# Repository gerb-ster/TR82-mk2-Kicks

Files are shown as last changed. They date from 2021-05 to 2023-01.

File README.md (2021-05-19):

# TR82 mk2 'Kicks'

Second version of the TR82 project; proper PCB's this time! I've combined the BassDrums and the SnareDrum to 
a single board. I've added a OpAmp buffer to the output and changed the output impedance to a more standard
1k. Next to that I've also added a Gate-to-Trigger circuit based on a design by Ken Stone. It converts the 
rising edge of a Gate signal into a short trigger pulse. By changin the level of the gate/trigger input you
can control how 'hard' you hit the drums. Higher levels means more 'accent'.

The Designs and Mods of the drum voices are the same as in the 'original' TR82.

There is a 'internal trigger' connection added to the mainboard of the PCB. This can be used to hook it up to
a seperate controller board. Maybe :). 

### Links

https://www.gerbster.nl/tr82/  
https://www.elby-designs.com/webtek/cgs/cgs24/cgs24_gatetotrigger.html

## Status: Work in Progress

- done: first schematic & board design
- done: breadboard and test
- done: design frontpanel
- todo: order PCB and build prototype

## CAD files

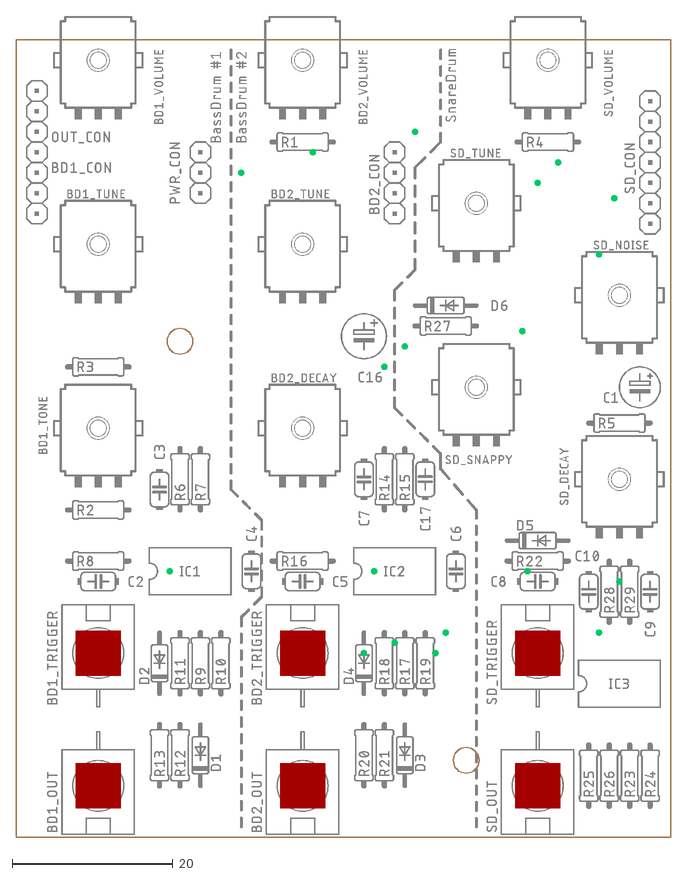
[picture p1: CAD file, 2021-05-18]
faceplates/ioboard.dxf
81.3 x 102.0

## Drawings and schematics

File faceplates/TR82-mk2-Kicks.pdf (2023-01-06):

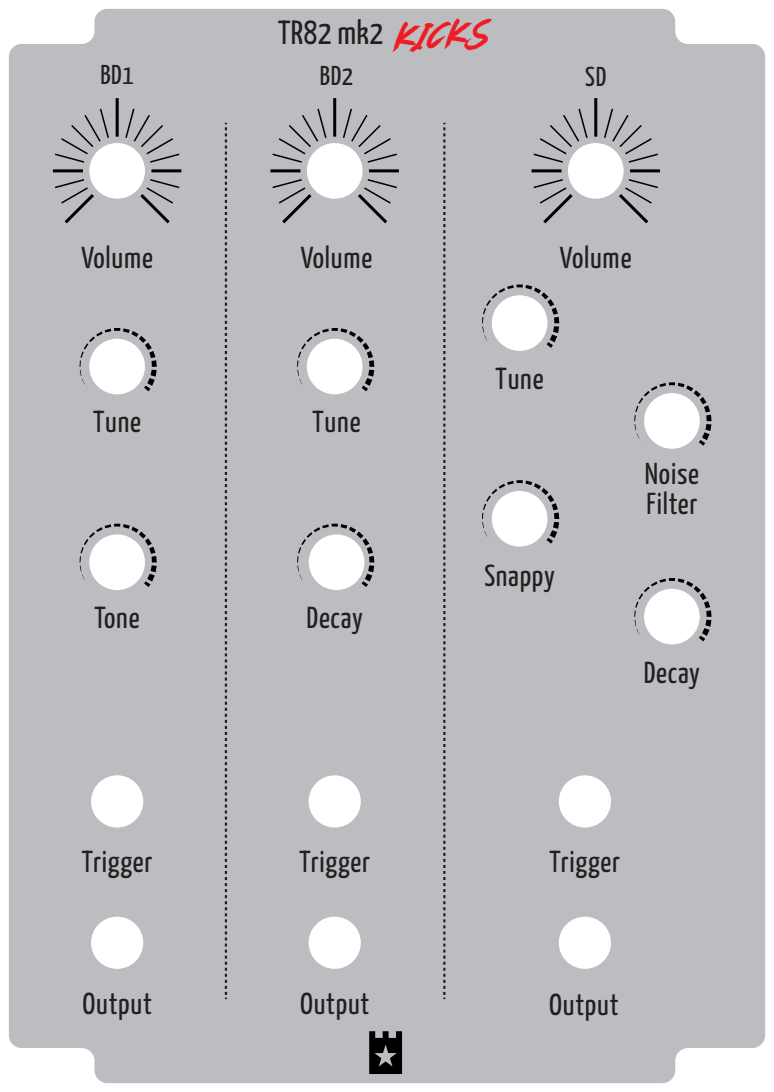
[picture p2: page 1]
Volume; Trigger; Output; Tune; Tone; Decay; Noise Filter; Snappy; Kicks

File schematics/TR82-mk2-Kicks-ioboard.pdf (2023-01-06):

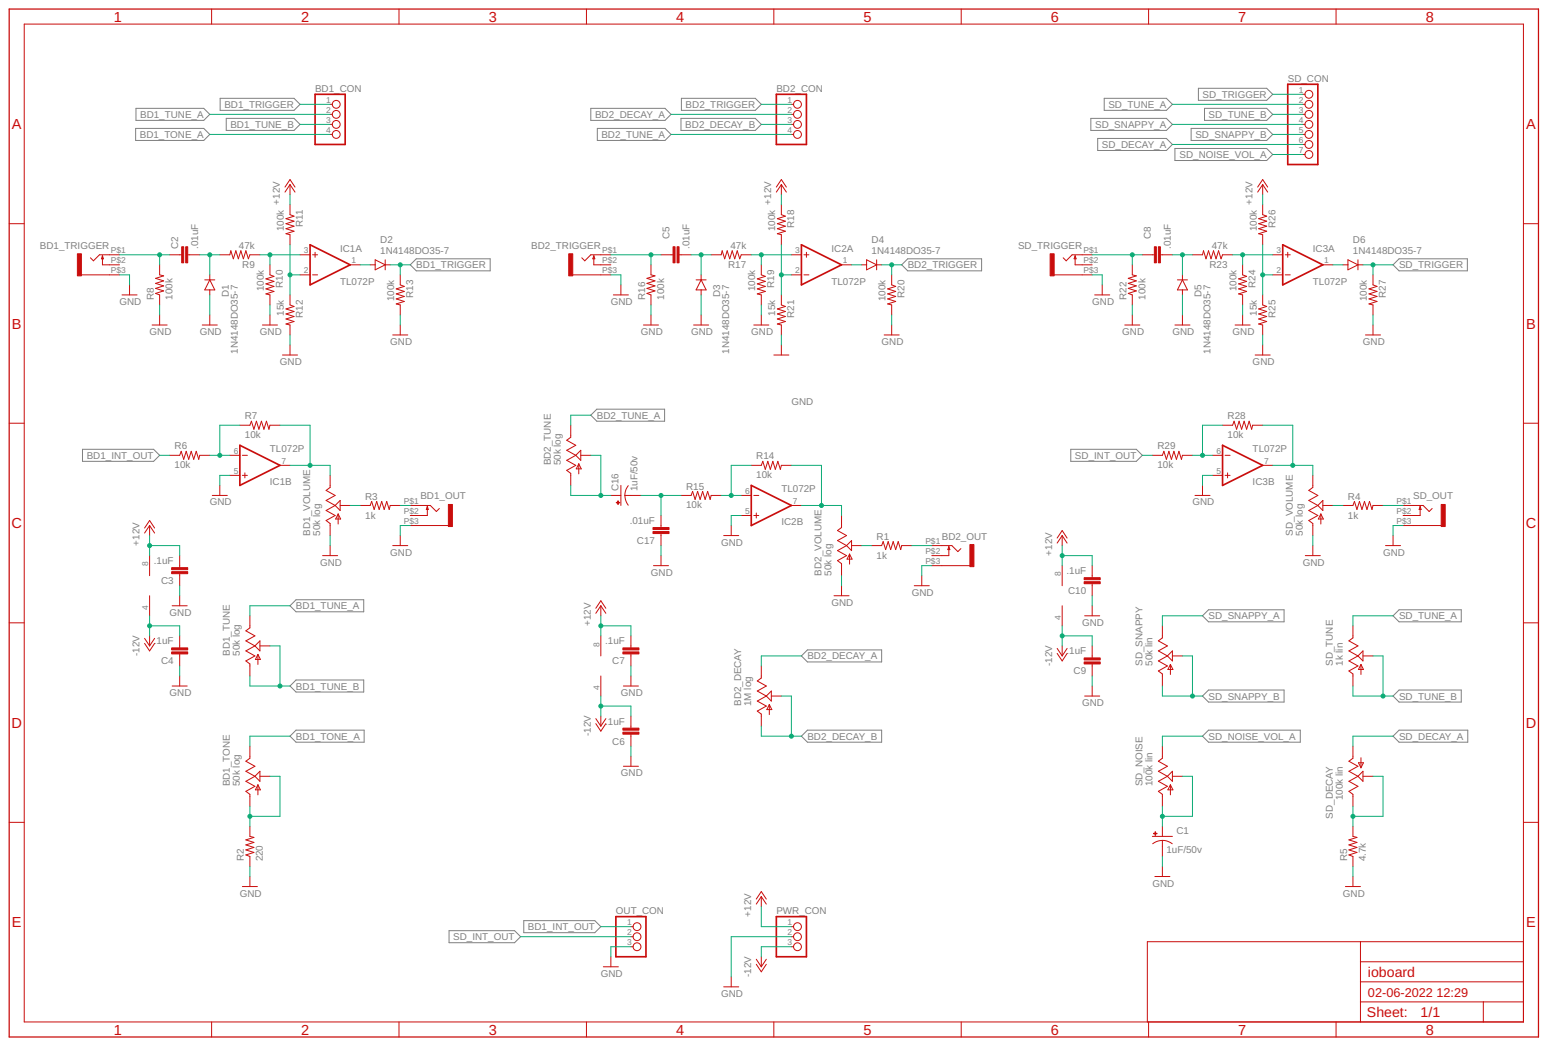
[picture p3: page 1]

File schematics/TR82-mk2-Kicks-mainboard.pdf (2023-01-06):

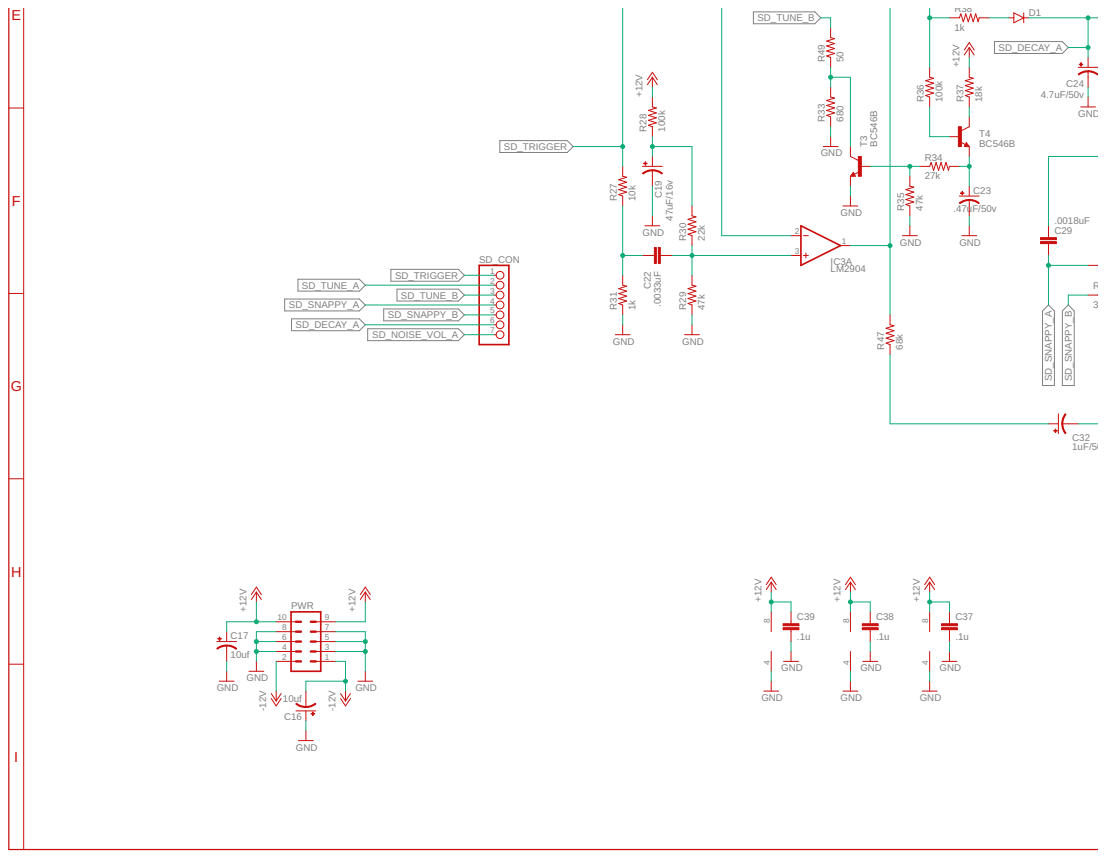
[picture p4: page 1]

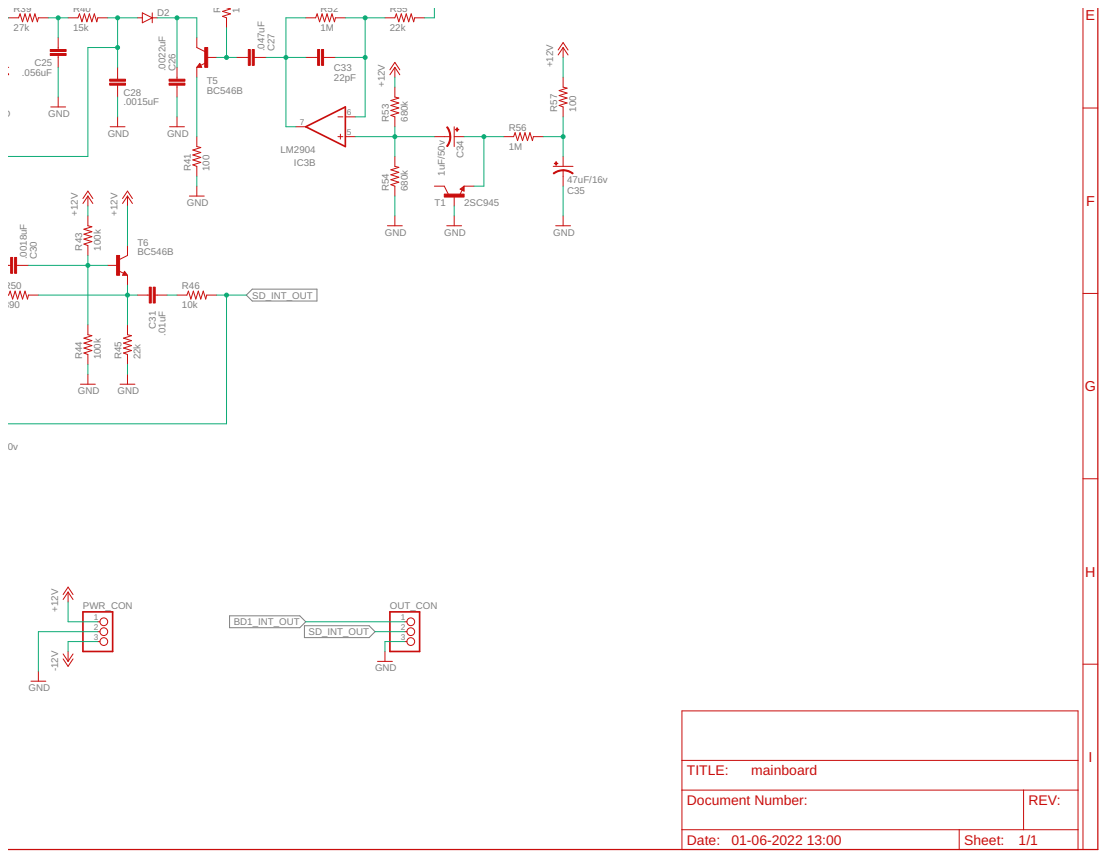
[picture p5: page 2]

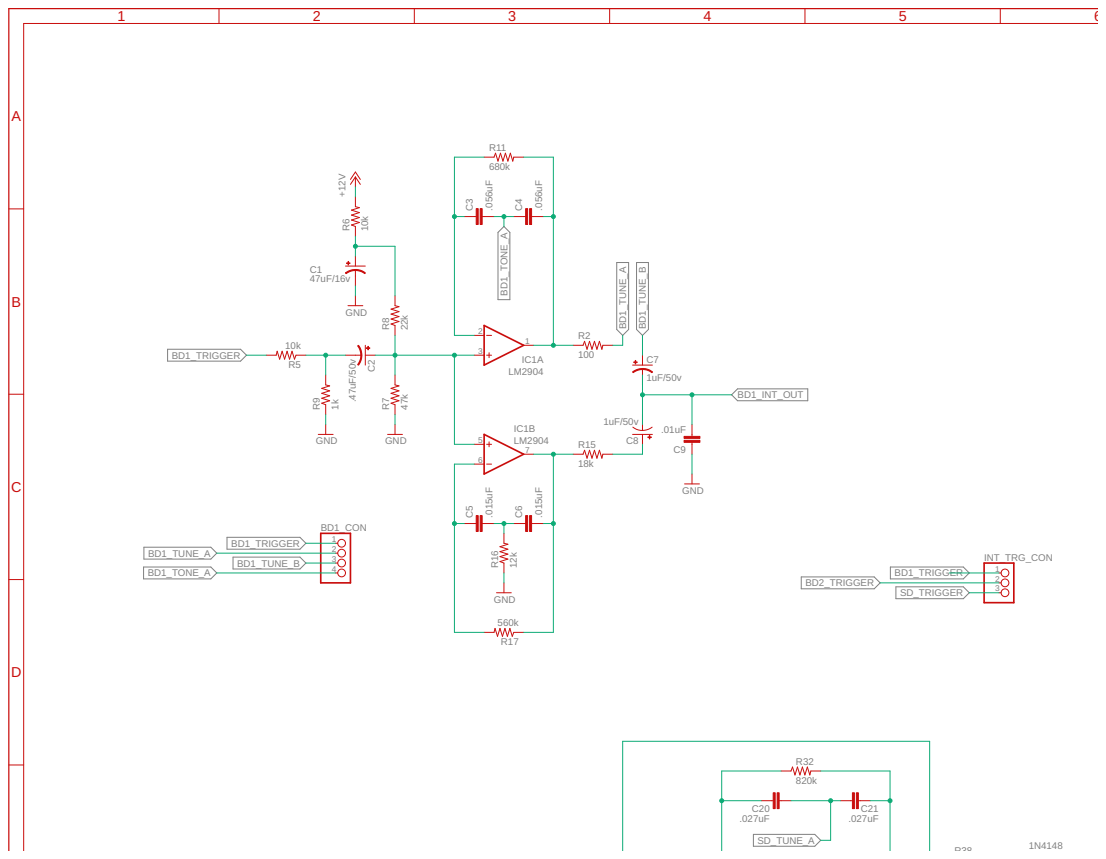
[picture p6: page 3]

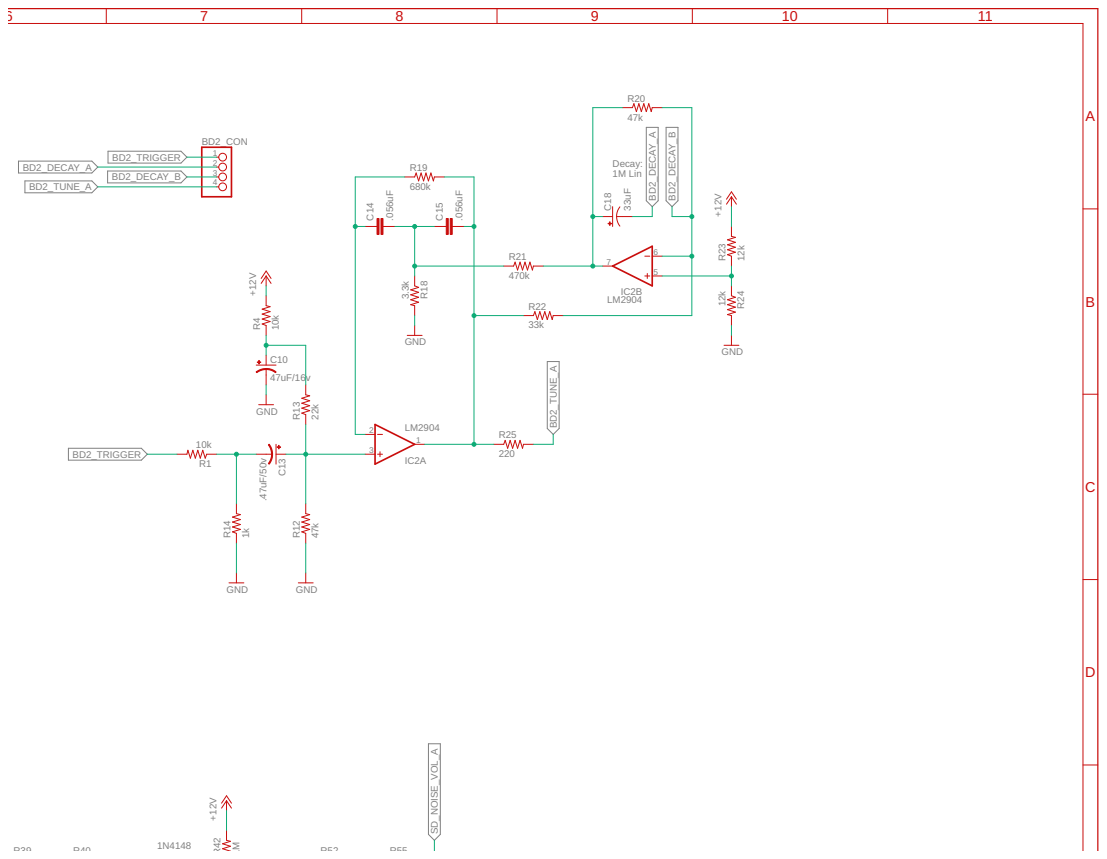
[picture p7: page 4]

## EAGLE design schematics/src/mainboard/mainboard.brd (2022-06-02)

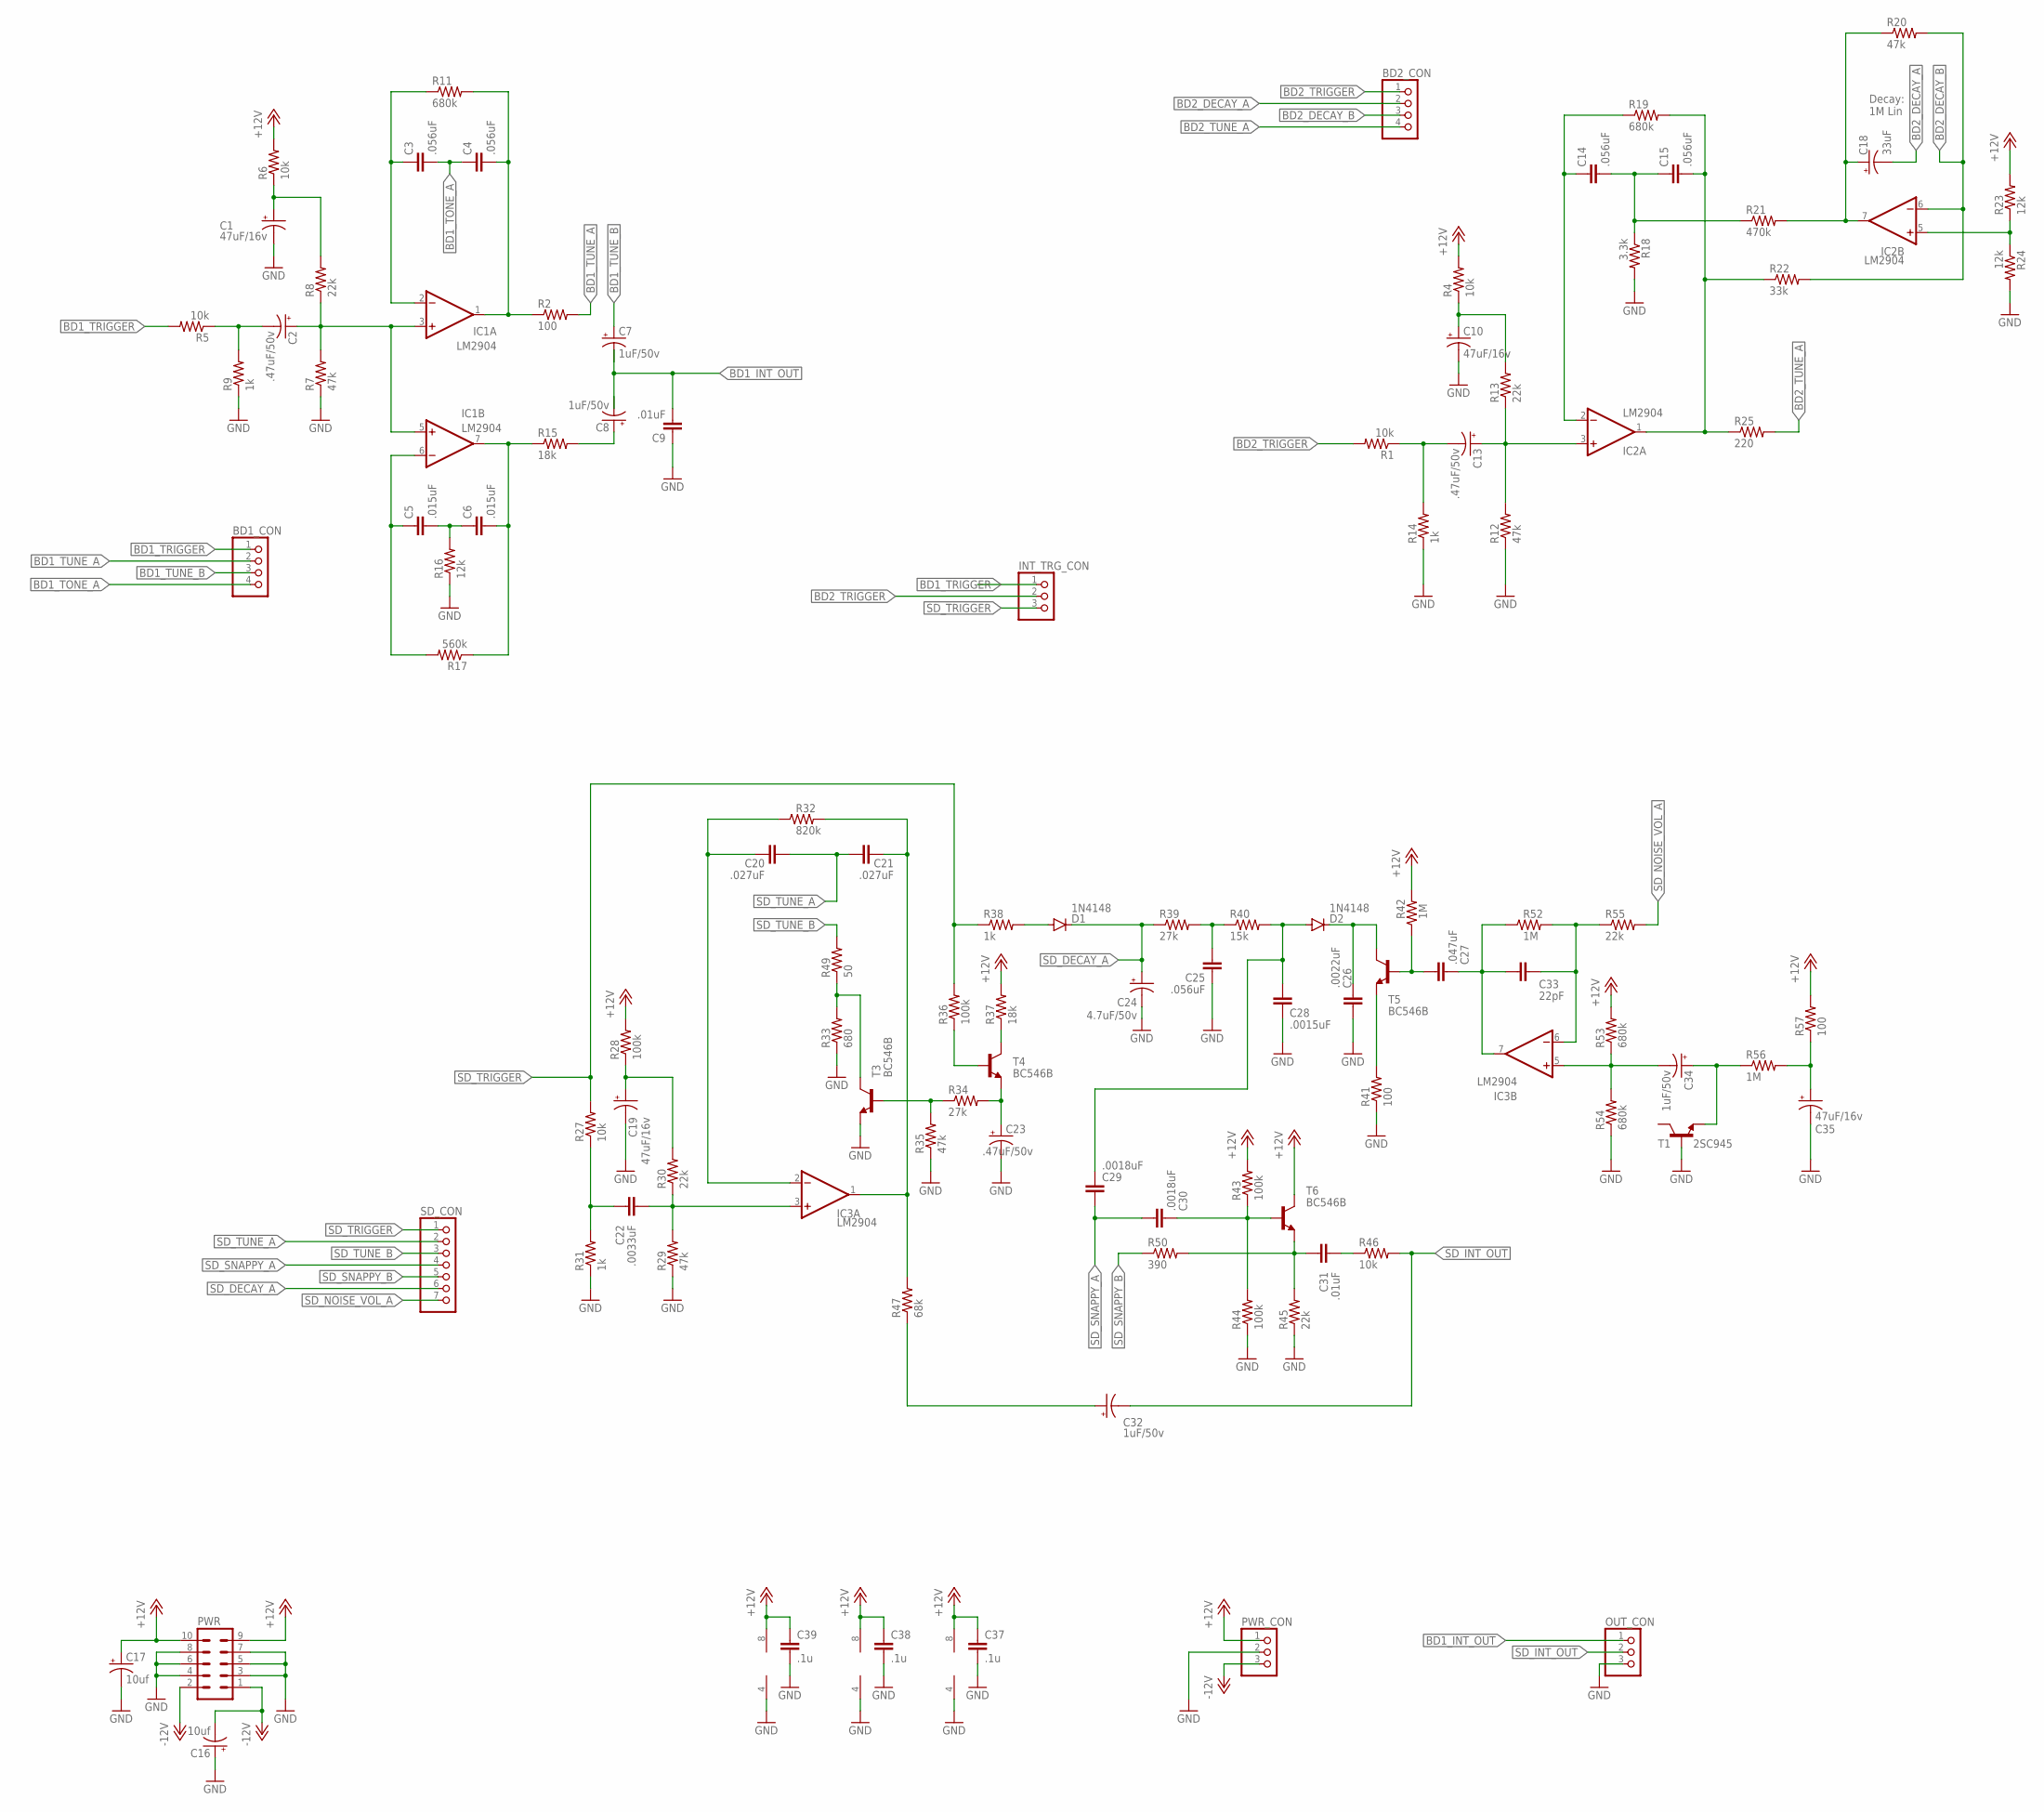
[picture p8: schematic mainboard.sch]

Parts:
BD1_CON, BD2_CON: PINHD-1X4; 1X04
C1, C35: 47uF/16v; E2,5-5
C2: .47uF/50v; E2,5-5
C3, C4, C14, C15, C25: .056uF; C050-024X044
C5, C6: .015uF; C050-024X044
C7, C8, C34: 1uF/50v; E2,5-5
C9, C31: .01uF; C050-024X044
C10, C19: 47uF/16v; E2,5-6
C13, C23: .47uF/50v; E2,5-6
C16, C17: 10uf; E2,5-5
C18: 33uF; E2,5-5
C20, C21: .027uF; C050-024X044
C22: .0033uF; C050-024X044
C24: 4.7uF/50v; E2,5-6
C26: .0022uF; C050-024X044
C27: .047uF; C050-024X044
C28: .0015uF; C050-024X044
C29, C30: .0018uF; C050-024X044
C32: 1uF/50v; E2,5-6
C33: 22pF; C050-024X044
C37, C38, C39: .1u; C050-024X044
D1, D2: 1N4148; DO35-7
IC1, IC2, IC3: LM2904; DIL08
INT_TRG_CON: PINHD-1X3; 1X03
OUT_CON: PINHD-1X3; 1X03
PWR: ML10
PWR_CON: PINHD-1X3; 1X03
R1, R4, R5, R6, R27, R46: 10k; 0207/7
R2, R41, R57: 100; 0207/7
R7, R12, R20, R29, R35: 47k; 0207/7
R8, R13, R30, R45, R55: 22k; 0207/7
R9, R14, R31, R38: 1k; 0207/7
R11, R19, R53, R54: 680k; 0207/7
R15, R37: 18k; 0207/7
R16, R23, R24: 12k; 0207/7
R17: 560k; 0207/7
R18: 3.3k; 0207/7
R21: 470k; 0207/7
R22: 33k; 0207/7
R25: 220; 0207/7
R28, R36, R43, R44: 100k; 0207/7
R32: 820k; 0207/2V
R33: 680; 0207/7
R34, R39: 27k; 0207/7
R40: 15k; 0207/7
R42, R52, R56: 1M; 0207/7
R47: 68k; 0207/7
R49: 50; 0207/7
R50: 390; 0207/7
SD_CON: PINHD-1X7; 1X07
T1: 2SC945; TO92-ECB
T3, T4, T5, T6: BC546B; TO92-CBE

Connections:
+12V: C17.+, C37.1, C38.1, C39.1, IC1.8 (V+), IC2.8 (V+), IC3.8 (V+), PWR.9, PWR.10, PWR_CON.1, R4.2, R6.2, R23.2, R28.2, R37.2, R42.2, R43.2, R53.2, R57.2, T6.C
-12V: C16.-, PWR.1, PWR.2, PWR_CON.3
BD1_INT_OUT: C7.-, C8.-, C9.2, OUT_CON.1
BD1_TONE_A: BD1_CON.4, C3.2, C4.1
BD1_TRIGGER: BD1_CON.1, INT_TRG_CON.1, R5.2
BD1_TUNE_A: BD1_CON.2, R2.2
BD1_TUNE_B: BD1_CON.3, C7.+
BD2_DECAY_A: BD2_CON.2, C18.-
BD2_DECAY_B: BD2_CON.3, IC2.6 (-IN), R20.2, R22.2
BD2_TRIGGER: BD2_CON.1, INT_TRG_CON.2, R1.2
BD2_TUNE_A: BD2_CON.4, R25.2
GND: C1.-, C9.1, C10.-, C16.+, C17.-, C19.-, C23.-, C24.-, C25.1, C26.1, C28.1, C35.-, C37.2, C38.2, C39.2, IC1.4 (V-), IC2.4 (V-), IC3.4 (V-), OUT_CON.3, PWR.3, PWR.4, PWR.5, PWR.6, PWR.7, PWR.8, PWR_CON.2, R7.1, R9.1, R12.1, R14.1, R16.1, R18.2, R24.2, R29.1, R31.1, R33.1, R35.1, R41.1, R44.1, R45.1, R54.1, T1.B, T3.E
unnamed: C13.-, R1.1, R14.2
unnamed: C2.-, R5.1, R9.2
unnamed: C2.+, IC1.3 (+IN), IC1.5 (+IN), R7.2, R8.1
unnamed: C1.+, R6.1, R8.2
unnamed: C5.2, C6.1, R16.2
unnamed: C3.1, IC1.2 (-IN), R11.1
unnamed: C13.+, IC2.3 (+IN), R12.2, R13.1
unnamed: C10.+, R4.1, R13.2
unnamed: C6.2, IC1.7 (OUT), R15.1, R17.1
unnamed: C5.1, IC1.6 (-IN), R17.2
unnamed: C4.2, IC1.1 (OUT), R2.1, R11.2
unnamed: C8.+, R15.2
unnamed: C14.1, IC2.2 (-IN), R19.1
unnamed: C14.2, C15.1, R18.1, R21.1
unnamed: C15.2, IC2.1 (OUT), R19.2, R22.1, R25.1
unnamed: C18.+, IC2.7 (OUT), R20.1, R21.2
unnamed: IC2.5 (+IN), R23.1, R24.1
unnamed: C22.1, R27.1, R31.2
unnamed: C22.2, IC3.3 (+IN), R29.2, R30.1
unnamed: C19.+, R28.1, R30.2
unnamed: C20.1, IC3.2 (-IN), R32.1
unnamed: C21.2, IC3.1 (OUT), R32.2, R47.2
unnamed: R33.2, R49.1, T3.C
unnamed: R34.1, R35.2, T3.B
unnamed: C23.+, R34.2, T4.E
unnamed: R36.1, T4.B
unnamed: R37.1, T4.C
unnamed: D1.A, R38.2
unnamed: C25.2, R39.2, R40.1
unnamed: C28.2, C29.1, D2.A, R40.2
unnamed: C26.2, D2.C, T5.C
unnamed: R41.2, T5.E
unnamed: C27.1, R42.1, T5.B
unnamed: C31.1, R45.2, R50.2, T6.E
unnamed: C31.2, R46.1
unnamed: C32.+, R47.1
unnamed: C30.2, R43.1, R44.2, T6.B
unnamed: C27.2, C33.1, IC3.7 (OUT), R52.1
unnamed: C33.2, IC3.6 (-IN), R52.2, R55.1
unnamed: C34.-, IC3.5 (+IN), R53.1, R54.2
unnamed: C34.+, R56.1, T1.E
unnamed: C35.+, R56.2, R57.1
SD_DECAY_A: C24.+, D1.C, R39.1, SD_CON.6
SD_INT_OUT: C32.-, OUT_CON.2, R46.2
SD_NOISE_VOL_A: R55.2, SD_CON.7
SD_SNAPPY_A: C29.2, C30.1, SD_CON.4
SD_SNAPPY_B: R50.1, SD_CON.5
SD_TRIGGER: INT_TRG_CON.3, R27.2, R36.2, R38.1, SD_CON.1
SD_TUNE_A: C20.2, C21.1, SD_CON.2
SD_TUNE_B: R49.2, SD_CON.3

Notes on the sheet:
Decay: 1M Lin

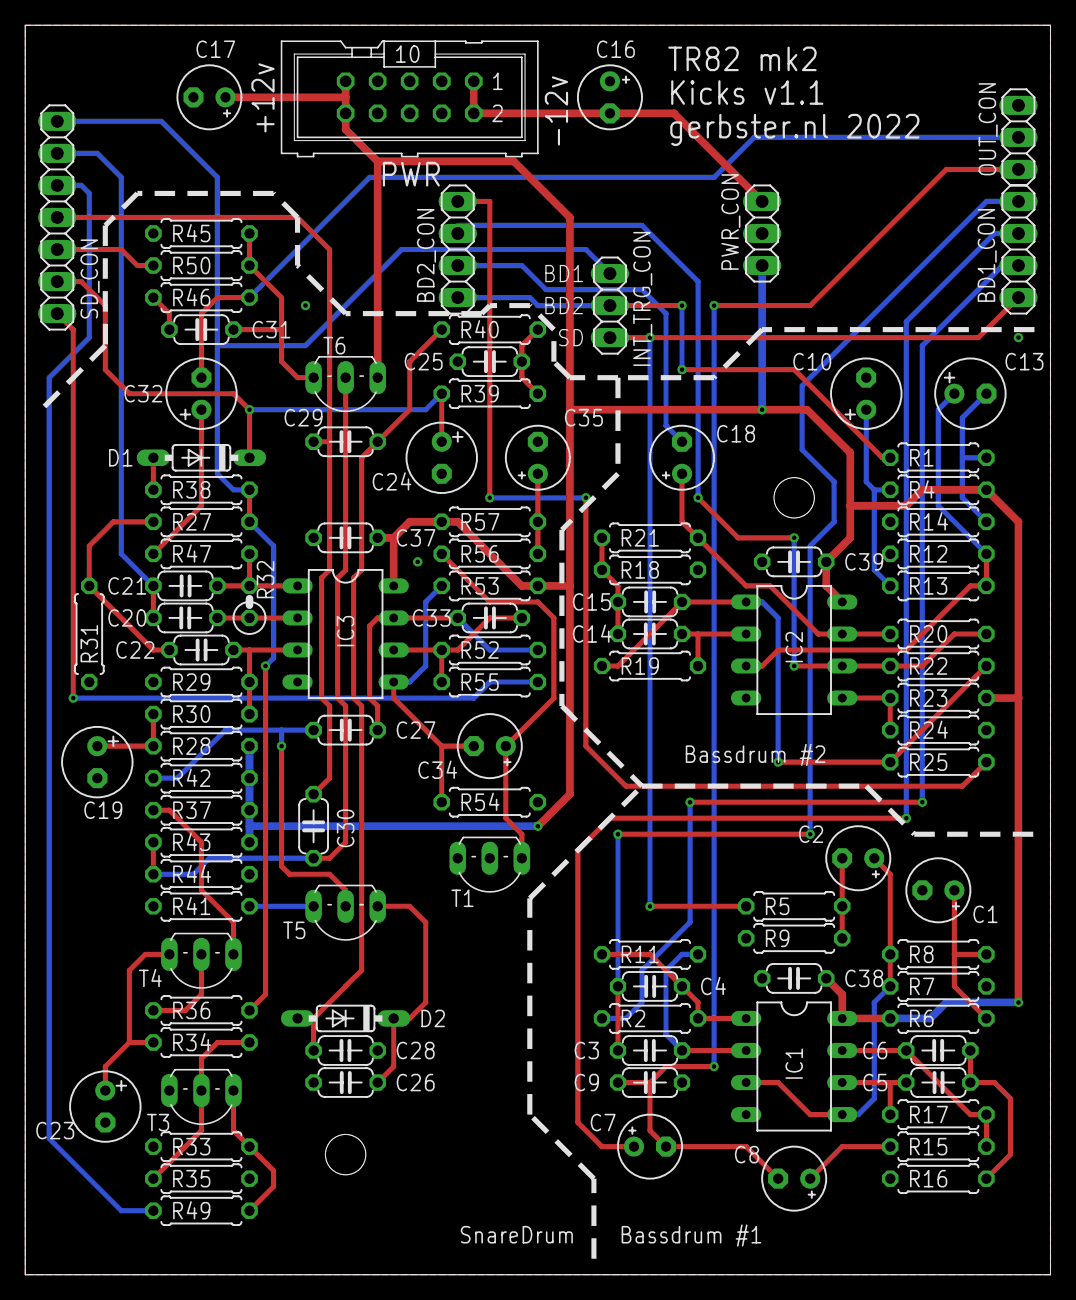
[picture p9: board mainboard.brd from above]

Board: 2 copper layers, 81.3 x 99.1 mm, 105 parts (0 on the bottom side), 62 nets.

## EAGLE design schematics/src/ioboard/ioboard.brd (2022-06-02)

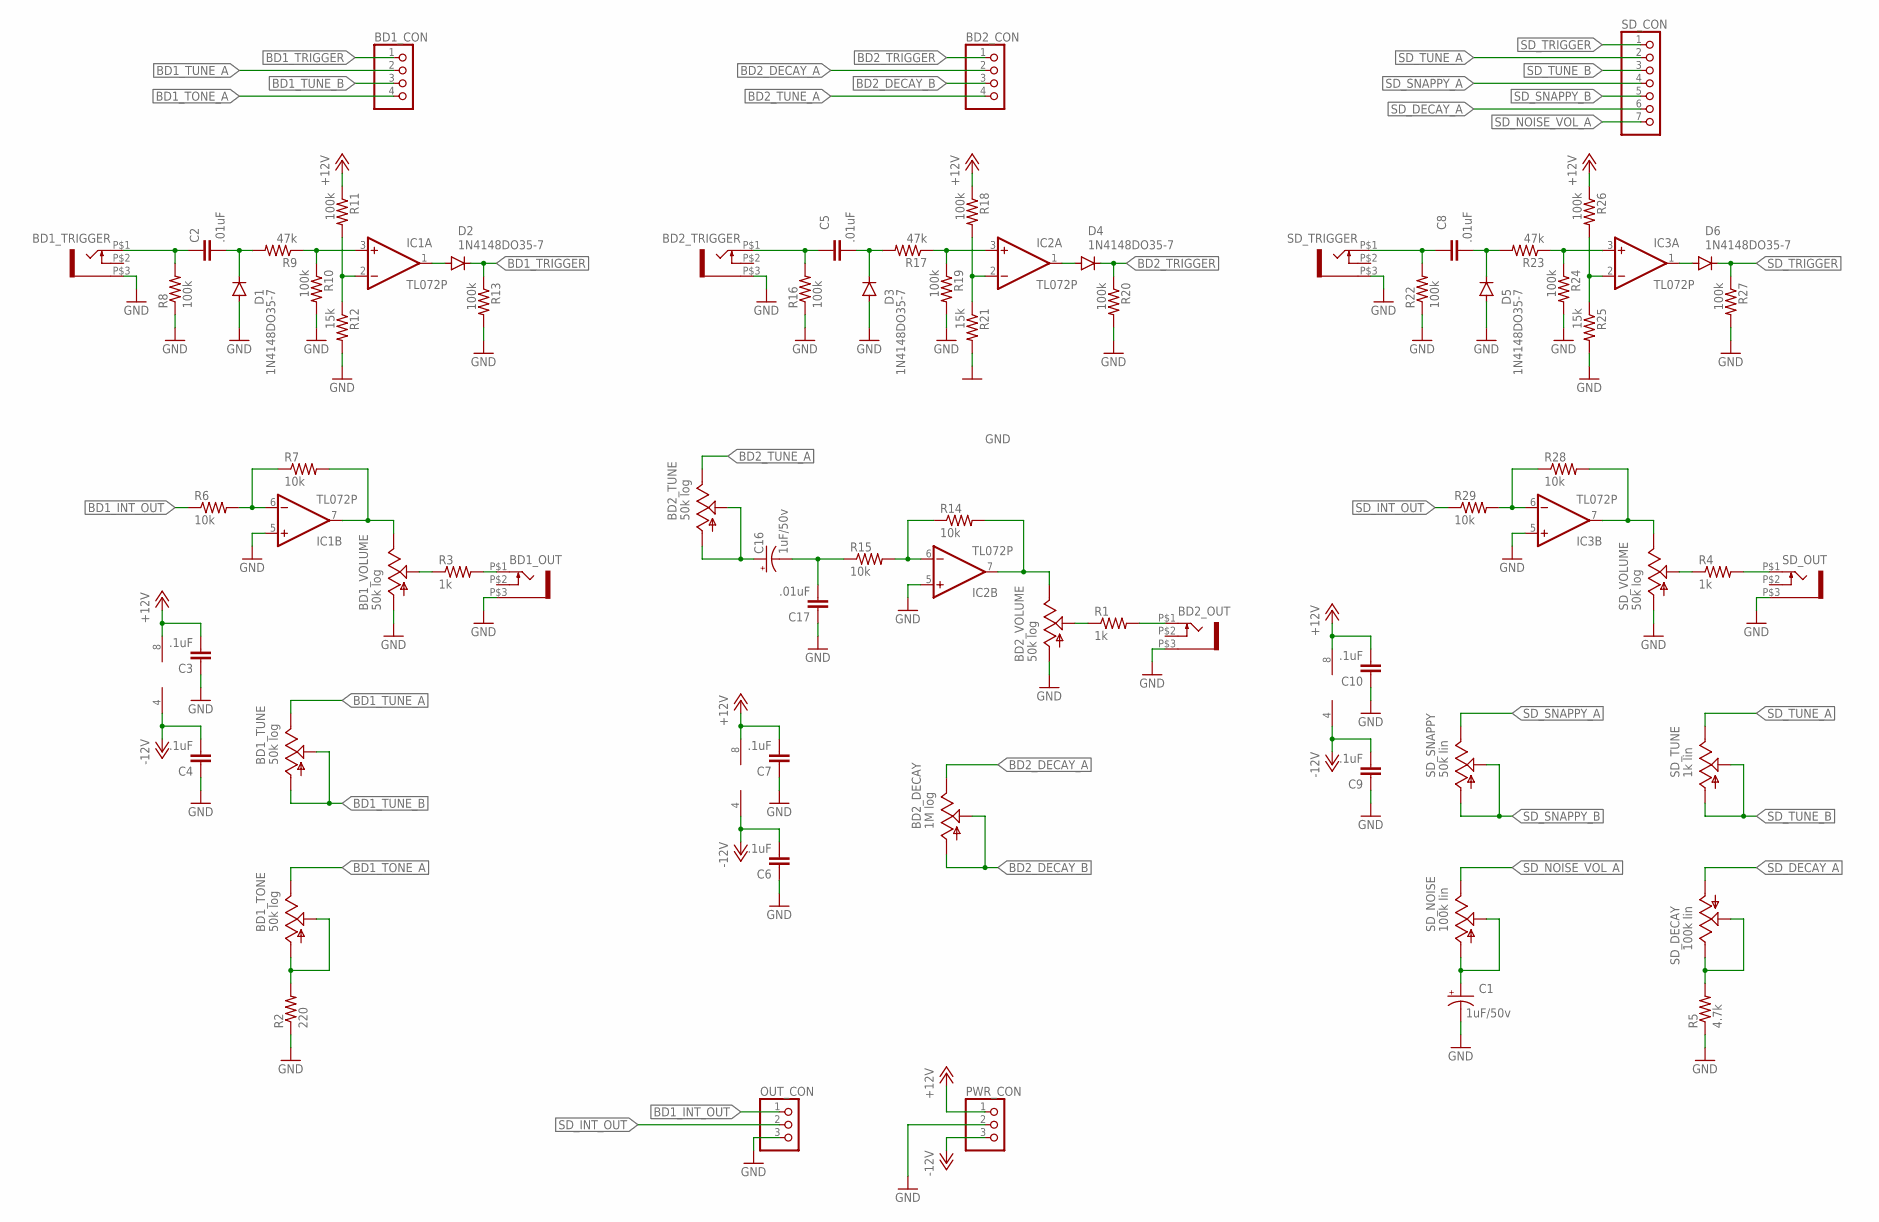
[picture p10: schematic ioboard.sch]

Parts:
BD1_CON, BD2_CON: PINHD-1X4; 1X04
BD1_OUT, BD1_TRIGGER, BD2_OUT, BD2_TRIGGER: WQP-PJ301M-12_JACK
BD1_TONE, BD1_TUNE, BD1_VOLUME, BD2_TUNE, BD2_VOLUME: 50k log; EVUF
BD2_DECAY: 1M log; EVUF
C1: 1uF/50v; E2,5-5
C2, C5, C8, C17: .01uF; C050-024X044
C3, C4, C6, C7, C9, C10: .1uF; C050-024X044
C16: 1uF/50v; E2,5-6
D1, D2, D3, D4, D5, D6: 1N4148DO35-7; DO35-7
IC1, IC2, IC3: TL072P; DIL08
OUT_CON: PINHD-1X3; 1X03
PWR_CON: PINHD-1X3; 1X03
R1, R3, R4: 1k; 0207/7
R2: 220; 0207/7
R5: 4.7k; 0207/7
R6, R7, R14, R15, R28, R29: 10k; 0207/7
R8, R10, R11, R13, R16, R18, R19, R20, R22, R24, R26, R27: 100k; 0207/7
R9, R17, R23: 47k; 0207/7
R12, R21, R25: 15k; 0207/7
SD_CON: PINHD-1X7; 1X07
SD_DECAY: 100k lin; EVUF
SD_NOISE: 100k lin; EVUF
SD_OUT: WQP-PJ301M-12_JACK
SD_SNAPPY: 50k lin; EVUF
SD_TRIGGER: WQP-PJ301M-12_JACK
SD_TUNE: 1k lin; EVUF
SD_VOLUME: 50k log; EVUF

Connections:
+12V: C3.2, C7.2, C10.2, IC1.8 (V+), IC2.8 (V+), IC3.8 (V+), PWR_CON.1, R11.1, R18.1, R26.1
-12V: C4.2, C6.2, C9.2, IC1.4 (V-), IC2.4 (V-), IC3.4 (V-), PWR_CON.3
BD1_INT_OUT: OUT_CON.1, R6.1
BD1_OUT: BD1_OUT.P$1 (2), R3.2
BD1_TONE_A: BD1_CON.4, BD1_TONE.3 (E)
BD1_TONE_B: BD1_TONE.1 (A), BD1_TONE.2 (S), R2.2
BD1_TRIGGER: BD1_CON.1, D2.C, R13.1
BD1_TUNE_A: BD1_CON.2, BD1_TUNE.3 (E)
BD1_TUNE_B: BD1_CON.3, BD1_TUNE.1 (A), BD1_TUNE.2 (S)
BD2_DECAY_A: BD2_CON.2, BD2_DECAY.3 (E)
BD2_DECAY_B: BD2_CON.3, BD2_DECAY.1 (A), BD2_DECAY.2 (S)
BD2_INT_OUT: C16.-, C17.2, R15.1
BD2_TRIGGER: BD2_CON.1, D4.C, R20.1
BD2_TUNE_A: BD2_CON.4, BD2_TUNE.3 (E)
BD2_TUNE_B: BD2_TUNE.1 (A), BD2_TUNE.2 (S), C16.+
GND: BD1_OUT.P$3 (1), BD1_TRIGGER.P$3 (1), BD1_VOLUME.1 (A), BD2_OUT.P$3 (1), BD2_TRIGGER.P$3 (1), BD2_VOLUME.1 (A), C1.-, C3.1, C4.1, C6.1, C7.1, C9.1, C10.1, C17.1, D1.A, D3.A, D5.A, IC1.5 (+IN), IC2.5 (+IN), IC3.5 (+IN), OUT_CON.3, PWR_CON.2, R2.1, R5.1, R8.1, R10.2, R12.2, R13.2, R16.1, R19.2, R20.2, R21.2, R22.1, R24.2, R25.2, R27.2, SD_OUT.P$3 (1), SD_TRIGGER.P$3 (1), SD_VOLUME.1 (A)
unnamed: BD1_VOLUME.2 (S), R3.1
unnamed: R4.1, SD_VOLUME.2 (S)
unnamed: BD2_OUT.P$1 (2), R1.2
unnamed: BD2_VOLUME.2 (S), R1.1
unnamed: R4.2, SD_OUT.P$1 (2)
unnamed: IC1.6 (-IN), R6.2, R7.1
unnamed: R5.2, SD_DECAY.2 (S), SD_DECAY.3 (E)
unnamed: BD1_TRIGGER.P$1 (2), C2.1, R8.2
unnamed: C2.2, D1.C, R9.2
unnamed: IC1.3 (+IN), R9.1, R10.1
unnamed: IC1.2 (-IN), R11.2, R12.1
unnamed: D2.A, IC1.1 (OUT)
unnamed: BD2_VOLUME.3 (E), IC2.7 (OUT), R14.2
unnamed: IC2.6 (-IN), R14.1, R15.2
unnamed: BD2_TRIGGER.P$1 (2), C5.1, R16.2
unnamed: C5.2, D3.C, R17.2
unnamed: IC2.3 (+IN), R17.1, R19.1
unnamed: D4.A, IC2.1 (OUT)
unnamed: IC3.6 (-IN), R28.1, R29.2
unnamed: IC2.2 (-IN), R18.2, R21.1
unnamed: C8.1, R22.2, SD_TRIGGER.P$1 (2)
unnamed: C8.2, D5.C, R23.2
unnamed: IC3.3 (+IN), R23.1, R24.1
unnamed: IC3.2 (-IN), R25.1, R26.2
unnamed: D6.A, IC3.1 (OUT)
unnamed: IC3.7 (OUT), R28.2, SD_VOLUME.3 (E)
unnamed: BD1_VOLUME.3 (E), IC1.7 (OUT), R7.2
SD_DECAY_A: SD_CON.6, SD_DECAY.1 (A)
SD_INT_OUT: OUT_CON.2, R29.1
SD_NOISE_B: C1.+, SD_NOISE.1 (A), SD_NOISE.2 (S)
SD_NOISE_VOL_A: SD_CON.7, SD_NOISE.3 (E)
SD_SNAPPY_A: SD_CON.4, SD_SNAPPY.3 (E)
SD_SNAPPY_B: SD_CON.5, SD_SNAPPY.1 (A), SD_SNAPPY.2 (S)
SD_TRIGGER: D6.C, R27.1, SD_CON.1
SD_TUNE_A: SD_CON.2, SD_TUNE.3 (E)
SD_TUNE_B: SD_CON.3, SD_TUNE.1 (A), SD_TUNE.2 (S)

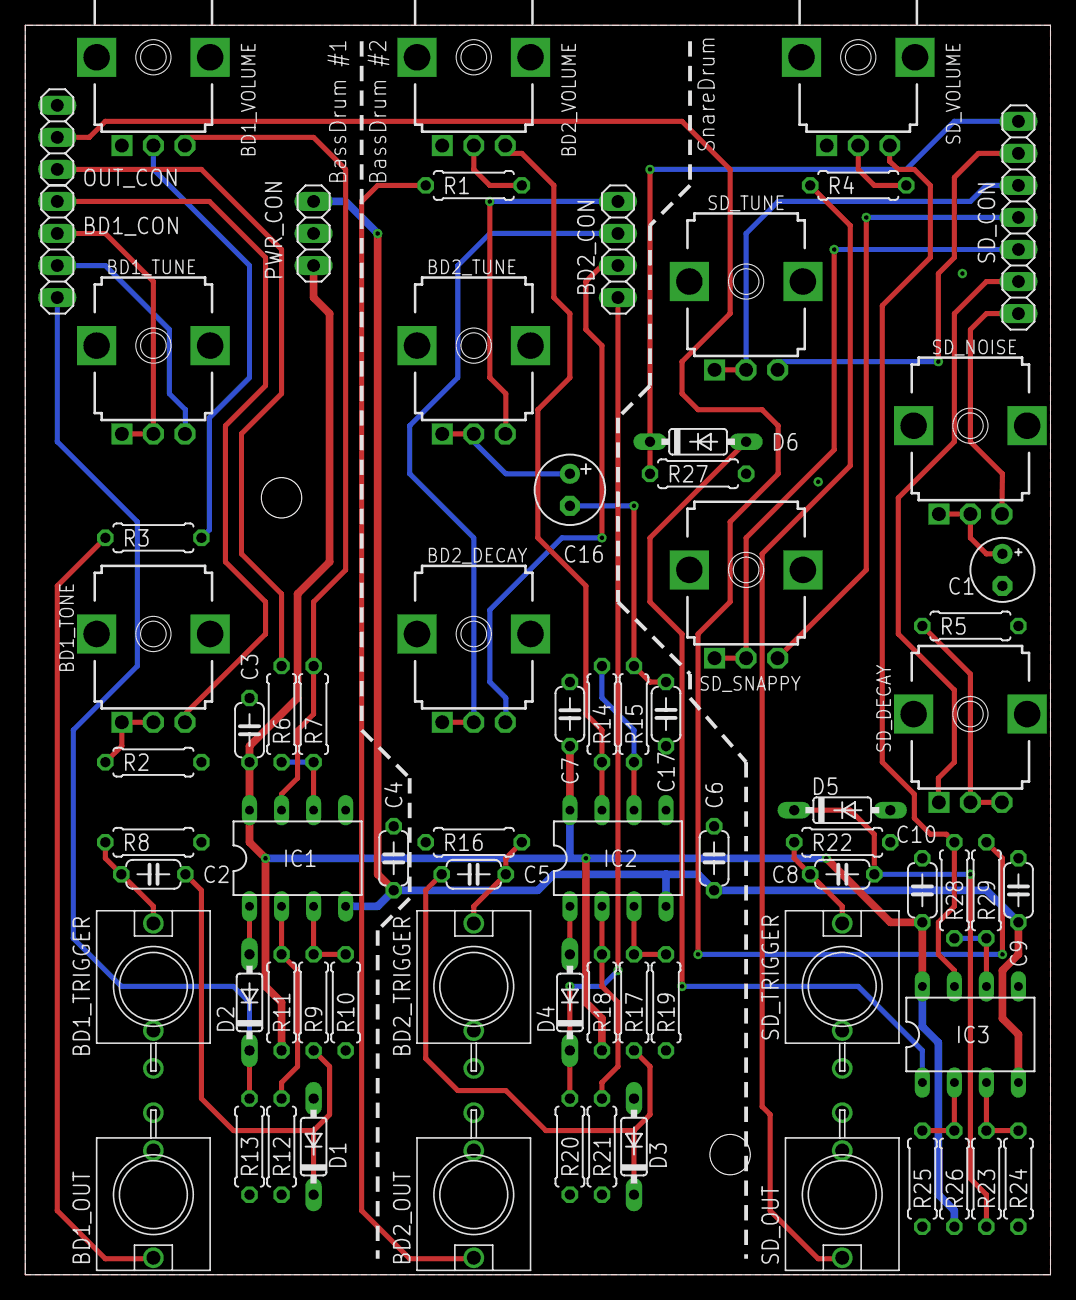
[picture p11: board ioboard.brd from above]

Board: 2 copper layers, 81.3 x 99.1 mm, 72 parts (0 on the bottom side), 52 nets.

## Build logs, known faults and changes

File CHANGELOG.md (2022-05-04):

# Changelog

All notable changes to this project will be documented in this file.

The format is based on [Keep a Changelog](https://keepachangelog.com/en/1.0.0/),
and this project adheres to [Semantic Versioning](https://semver.org/spec/v2.0.0.html).

## [1.1.0] - 2022-14-04

### Changed

- Fixed wrong header positions
- Fixed SD output
- Fixed gate-to-trigger issue

## [1.0.0] - 2021-18-05

### Added

- Inintial repo setup

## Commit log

2021-05-18 Added Faceplates
    [TR82-mk2-Kicks-ioboard.GBL, TR82-mk2-Kicks-ioboard.GBO, TR82-mk2-Kicks-ioboard.GBP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]
2021-05-18 Added faceplate design setup
    [ioboard.dxf, mainboard.brd]
2021-05-19 Updated Schematics & Readme
    [TR82-mk2-Kicks-ioboard.XLN, TR82-mk2-Kicks-mainboard.GBL, TR82-mk2-Kicks-mainboard.GBS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]
2021-06-07 Updated Schematics & Firmware
2021-06-15 Updated Schematics, Fixed Power Socket orientation
    [TR82-mk2-Kicks-ioboard.GBL, TR82-mk2-Kicks-ioboard.GTO, TR82-mk2-Kicks-ioboard.XLN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]
2021-07-19 Fixed minor issues, added documentation and updated some faceplates
    [mainboard.brd]
2021-08-06 Updated some schematics and docs
    [TR82-mk2-Kicks-ioboard.GBL, TR82-mk2-Kicks-ioboard.GBO, TR82-mk2-Kicks-ioboard.GBP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]
2021-08-10 Fixed some bugs and updated documentation
    [TR82-mk2-Kicks-ioboard.XLN, TR82-mk2-Kicks-mainboard.XLN, gerber_job.gbrjob]
2022-04-20 Some updates & bugfixes
    [TR82-mk2-Kicks-ioboard.GBL, TR82-mk2-Kicks-ioboard.GBS, TR82-mk2-Kicks-ioboard.GTL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]
2022-04-22 Fixed schematics & descriptions
    [TR82-mk2-Kicks-ioboard.XLN, TR82-mk2-Kicks-mainboard.XLN, gerber_job.gbrjob]
2022-05-17 Updated Firmware
    [TR82-mk2-Kicks-ioboard.XLN, TR82-mk2-Kicks-mainboard.XLN, gerber_job.gbrjob]
2022-05-18 Updated Faceplates
    [TR82-mk2-Kicks-ioboard.XLN, TR82-mk2-Kicks-mainboard.XLN, gerber_job.gbrjob]
2022-05-18 Fixed issues
    [TR82-mk2-Kicks-ioboard.XLN, TR82-mk2-Kicks-mainboard.XLN, gerber_job.gbrjob]
2022-05-21 Fixed schematics
    [TR82-mk2-Kicks-ioboard.XLN, TR82-mk2-Kicks-mainboard.XLN, gerber_job.gbrjob]
2022-05-28 General updates
    [TR82-mk2-Kicks-ioboard.GKO, TR82-mk2-Kicks-mainboard.GKO, copper_bottom.gbr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]
2022-06-02 Fixed orentation SD Decay pot
    [ioboard.brd, ioboard.sch, mainboard.brd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]
2022-06-13 Updated FacePlate designs
    [drills.xln, gerber_job.gbrjob]
